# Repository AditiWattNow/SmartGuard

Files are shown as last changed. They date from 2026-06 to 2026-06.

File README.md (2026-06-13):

# SmartGuard — AI-Powered Railway Platform Crowd Safety System

> **Hackathon Project** | Hardware + Software | Indian Railways Safety Track

SmartGuard Dashboard

## The Problem

On **February 15, 2025**, a crowd crush at New Delhi Railway Station killed **18 people** and injured 15 others — triggered by train delays creating dangerous platform overcrowding. Indian Railways subsequently identified **60 high-traffic stations** requiring immediate crowd management upgrades.

Existing solutions react *after* dangerous density is reached. SmartGuard **predicts** breaches before they happen.

---

## What SmartGuard Does

| Layer | What it is |
|---|---|
| **Hardware** | Custom PCB sensor node (ESP32-S3 + PIR + ToF + LoRa) per zone |
| **Backend** | FastAPI server with time-series crowd data + anomaly detection |
| **Dashboard** | Live SVG station map + real-time alerts + trend prediction |
| **AI Model** | Linear regression slope on 5-reading window → estimated minutes to breach |

**Key differentiator:** SmartGuard gives station operators an **8–15 minute warning** before a dangerous threshold is reached — time to open alternate gates, redirect crowds, or delay train boarding. Real-time monitoring only tells you what's *already* happening.

---

## Architecture

```
[ESP32-S3 Node] ──WiFi/LoRa──▶ [FastAPI Backend] ──REST──▶ [Dashboard]
    ↑                                   ↓
PIR + VL53L1X                    SQLite DB
sensors                          Prediction Engine
                                 Alert Generator
```

**Kavach 4.0 compatible:** SmartGuard data format is designed for integration with Indian Railways' existing Kavach ATP system API. Kavach prevents train collisions — SmartGuard prevents platform crush. They are complementary, not competing.

---

## Repository Structure

```
smartguard/
├── backend/
│   ├── main.py              # FastAPI server — all 4 endpoints
│   └── requirements.txt
├── firmware/
│   └── smartguard_node.ino  # ESP32-S3 Arduino sketch
├── frontend/
│   └── index.html           # Complete single-file dashboard
├── hardware/                # KiCad PCB project (your partner's domain)
│   ├── smartguard_node.kicad_sch
│   ├── smartguard_node.kicad_pcb
│   └── gerbers/
└── docs/
    ├── architecture.png
    └── deployment-spec.md
```

---

## Running Locally

### Backend

```bash
cd backend
pip install -r requirements.txt
uvicorn main:app --reload --host 0.0.0.0 --port 8000
```

The server starts with:
- **Seeded historical data** (2 hours of realistic crowd patterns)
- **Mock sensor simulator** running in background — no hardware needed for demo
- **SQLite database** (`smartguard.db`) auto-created on first run

### Frontend

Just open `frontend/index.html` in a browser. No build step needed.

> If you get CORS errors, make sure the backend is running on `localhost:8000` (default).  
> For deployment, update `const API = "..."` in `index.html` to your server URL.

---

## API Endpoints

| Method | Endpoint | Description |
|---|---|---|
| `POST` | `/sensor` | Receive data from ESP32 nodes |
| `GET`  | `/zones` | Live crowd state for all zones |
| `GET`  | `/history/{zone_id}?minutes=60` | Time-series data for chart |
| `GET`  | `/alerts?limit=20` | Recent alert feed |
| `GET`  | `/stats/summary` | Header KPI cards |

### Example sensor POST (from ESP32 or test):
```bash
curl -X POST http://localhost:8000/sensor \
  -H "Content-Type: application/json" \
  -d '{"zone_id": "P1", "count": 145}'
```

---

## Zone Configuration

Zones are defined in `backend/main.py`:

```python
ZONES = {
    "P1": {"name": "Platform 1 - Gate A", "capacity": 200, ...},
    "P2": {"name": "Platform 2 - Gate B", "capacity": 180, ...},
    "C1": {"name": "Central Concourse",   "capacity": 400, ...},
    ...
}

THRESHOLDS = {"safe": 0.60, "warning": 0.80}  # fraction of capacity
```

Modify these to match any real station's layout.

---

## Prediction Model

SmartGuard uses a **least-squares linear regression** on the 10 most recent readings per zone:

1. Compute slope (people/second) from the time-series
2. If slope is positive, estimate seconds until 80% capacity threshold
3. Convert to minutes and surface in the UI as "Breach in ~N min"

This is equivalent to `sklearn.linear_model.LinearRegression` on a rolling window. For production, this can be upgraded to `IsolationForest` for anomaly detection or an LSTM for multi-step forecasting.

---

## Hardware BOM (per node) — ~₹2,500

| Component | Part | ~Cost |
|---|---|---|
| MCU | ESP32-S3 DevKitC | ₹800 |
| Motion sensor × 2 | HC-SR501 PIR | ₹80 |
| Distance sensor | VL53L1X ToF | ₹350 |
| Radio | SX1276 LoRa module | ₹450 |
| Battery management | TP4056 IC | ₹40 |
| PCB fabrication (JLCPCB) | 4-layer, 5 units | ₹600 |
| Misc (caps, LEDs, headers) | — | ₹180 |

**60 stations × avg 8 nodes = 480 nodes × ₹2,500 = ₹12 lakh total hardware cost.**
This is the cost of one Kavach installation on a 1km track segment.

---

## Deployment Path

1. **Phase 1 — Pilot** (3 months): Install at 2 platforms of New Delhi station. Validate prediction accuracy against manual crowd counts.
2. **Phase 2 — Refinement** (3 months): Tune thresholds, integrate train delay API for better surge prediction.
3. **Phase 3 — Rollout** (6 months): Deploy to 60 identified high-risk stations. Integrate alerts into station master control room.

---

## Team

| Role | Responsibility |
|---|---|
| Hardware Engineer | PCB design (KiCad), ESP32 firmware, sensor integration |
| Software Engineer | FastAPI backend, React dashboard, deployment |

---

## License

MIT License — open for Indian Railways adoption and modification.

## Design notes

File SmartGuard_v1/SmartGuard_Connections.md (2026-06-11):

# SmartGuard v1 — PCB Connection Reference

## Project Overview
AI-powered railway platform crowd crush prevention system.
Custom PCB sensor node for real-time crowd density monitoring.

---

## Bill of Materials (BOM)

| Ref | Component | Package | Value | Source |
|-----|---|---|---|---|
| U1 | ESP32-S3-WROOM-1 | SMD Castellated | Main MCU | Robu.in |
| U2 | VL53L1X Breakout | 6-pin header | ToF depth sensor | Thingbits.in |
| U3 | RFM95W-868S2 | SMD Module | LoRa 868MHz radio | Evelta.com |
| U4 | TP4056 Module | External module | LiPo charger 1A | Robu.in |
| U5 | LM7833 / AMS1117-3.3 | TO-220 THT | 3.3V LDO regulator | SP Road |
| R1 | Resistor | THT axial | 10kΩ | SP Road |
| R2 | Resistor | THT axial | 4.7kΩ | SP Road |
| R3 | Resistor | THT axial | 4.7kΩ | SP Road |
| R4 | Resistor | THT axial | 100Ω | SP Road |
| R5 | Resistor | THT axial | 1.2kΩ | SP Road |
| R6 | Resistor | THT axial | 100Ω | SP Road |
| R7 | Resistor | THT axial | 100Ω | SP Road |
| C1 | Ceramic Cap | THT disc | 100nF | SP Road |
| C2 | Ceramic Cap | THT disc | 100nF | SP Road |
| C3 | Ceramic Cap | THT disc | 100nF | SP Road |
| C4 | Electrolytic Cap | THT radial | 10µF | SP Road |
| C5 | Ceramic Cap | THT disc | 100nF | SP Road |
| D1 | LED Red | THT 5mm | Status indicator | SP Road |
| D2 | LED Amber | THT 5mm | Status indicator | SP Road |
| D3 | LED Green | THT 5mm | Status indicator | SP Road |
| J1 | PIR-A Connector | PinHeader 2.54mm 3-pin | HC-SR501 Zone A | SP Road |
| J2 | PIR-B Connector | PinHeader 2.54mm 3-pin | HC-SR501 Zone B | SP Road |
| J4 | LiPo Connector | JST-PH 2mm 2-pin | 3.7V 2000mAh battery | Robu.in |
| AE1 | Antenna | SMA EdgeMount | 868MHz wire antenna | SP Road |
| — | HC-SR501 × 2 | External module | PIR motion sensors | Robu.in |

**Estimated total cost: ₹2000–2500**

---

## Pin Assignments — ESP32-S3-WROOM-1

### I2C Bus (VL53L1X ToF sensor)
| ESP32-S3 Pin | Signal | Connected To |
|---|---|---|
| IO4 | I2C_SDA | VL53L1X SDA + 4.7kΩ pullup to 3V3 |
| IO5 | I2C_SCL | VL53L1X SCL + 4.7kΩ pullup to 3V3 |
| IO8 | TOF_XSHUT | VL53L1X XSHUT |

### SPI Bus (RFM95W LoRa)
| ESP32-S3 Pin | Signal | Connected To |
|---|---|---|
| IO18 | SPI_MOSI | RFM95W MOSI |
| IO35 | SPI_MISO | RFM95W MISO |
| IO38 | SPI_SCK | RFM95W SCK |
| IO21 | LORA_NSS | RFM95W NSS (chip select) |
| IO41 | LORA_RST | RFM95W RESET |
| IO9 | LORA_DIO0 | RFM95W DIO0 (interrupt) |

### GPIO (PIR sensors)
| ESP32-S3 Pin | Signal | Connected To |
|---|---|---|
| IO6 | PIR_A | HC-SR501 Zone A OUT |
| IO7 | PIR_B | HC-SR501 Zone B OUT |

### GPIO (Status LEDs)
| ESP32-S3 Pin | Signal | Connected To |
|---|---|---|
| IO46 | LED_RED | 100Ω resistor → Red LED anode |
| IO42 | LED_AMB | 100Ω resistor → Amber LED anode |
| IO47 | LED_GRN | 100Ω resistor → Green LED anode |

### Power
| ESP32-S3 Pin | Connected To |
|---|---|
| 3V3 | +3V3 power rail |
| GND | GND |
| EN | 10kΩ pullup to +3V3 |

---

## VL53L1X Breakout Board Connections

| VL53L1X Pin | Connected To |
|---|---|
| VDD | +3V3 |
| GND | GND |
| SDA | I2C_SDA (IO4) |
| SCL | I2C_SCL (IO5) |
| XSHUT | TOF_XSHUT (IO8) |
| GPIO1 | Not connected |

**I2C Address:** 0x29

---

## RFM95W-868S2 LoRa Module Connections

| RFM95W Pin | Connected To |
|---|---|
| 3.3V | +3V3 |
| GND | GND |
| MOSI | SPI_MOSI (IO18) |
| MISO | SPI_MISO (IO35) |
| SCK | SPI_SCK (IO38) |
| NSS | LORA_NSS (IO21) |
| RESET | LORA_RST (IO41) |
| DIO0 | LORA_DIO0 (IO9) |
| ANT | 8.2cm wire antenna (868MHz) |
| DIO1–DIO5 | Not connected |

**Frequency:** 868 MHz (India ISM band approved)
**Antenna:** 8.2cm straight wire for 868MHz λ/4

---

## HC-SR501 PIR Sensor Connections (×2)

| HC-SR501 Pin | Zone A | Zone B |
|---|---|---|
| VCC | +5V | +5V |
| GND | GND | GND |
| OUT | PIR_A (IO6) | PIR_B (IO7) |

**Note:** HC-SR501 OUT is 3.3V logic — safe for direct ESP32 GPIO connection.
**Sensitivity:** Adjust onboard potentiometer to ~3 metre range.
**Delay:** Set onboard delay pot to minimum (~5 seconds).

---

## Power Section

### TP4056 Charging Module
| TP4056 Module Pin | Connected To |
|---|---|
| USB input | External USB-C/Micro-USB (onboard) |
| B+ | LiPo battery positive (JST J4 pin 1) |
| B- | LiPo battery negative (JST J4 pin 2) / GND |
| OUT+ (VBAT) | LM7833 input (VI pin) |
| OUT- | GND |

**Charge current:** 1A (set by 1.2kΩ PROG resistor)

### LM7833 / AMS1117-3.3 Voltage Regulator (TO-220)
| LM7833 Pin | Connected To |
|---|---|
| VI (input) | VBAT from TP4056 OUT+ |
| VO (output) | +3V3 power rail |
| GND | GND |

**Input cap:** 10µF (C4) from VBAT to GND
**Output cap:** 100nF (C5) from +3V3 to GND

---

## Decoupling Capacitors

| Cap | Value | Placed Near | Between |
|---|---|---|---|
| C1 | 100nF | VL53L1X VDD pin | +3V3 and GND |
| C2 | 100nF | RFM95W 3.3V pin | +3V3 and GND |
| C3 | 100nF | TP4056 VCC pin | +5V and GND |
| C4 | 10µF | LM7833 input | VBAT and GND |
| C5 | 100nF | LM7833 output | +3V3 and GND |

---

## I2C Pull-up Resistors

| Resistor | Value | Connected Between |
|---|---|---|
| R2 | 4.7kΩ | I2C_SDA and +3V3 |
| R3 | 4.7kΩ | I2C_SCL and +3V3 |

---

## Status LED Circuit

| LED | Color | Resistor | GPIO |
|---|---|---|---|
| D1 | Red | R4 100Ω | IO46 |
| D2 | Amber | R6 100Ω | IO42 |
| D3 | Green | R7 100Ω | IO47 |

**Meaning:**
- 🟢 Green = Safe — crowd density normal
- 🟡 Amber = Warning — density rising, monitor
- 🔴 Red = Alert — critical density, trigger PA system

---

## Firmware Pin Definitions

```cpp
// ============================================
// SmartGuard v1 — Pin Definitions
// ESP32-S3-WROOM-1
// ============================================

// I2C — VL53L1X ToF sensor
#define I2C_SDA     4
#define I2C_SCL     5
#define TOF_XSHUT   8

// SPI — RFM95W LoRa
#define LORA_MOSI   18
#define LORA_MISO   35
#define LORA_SCK    38
#define LORA_NSS    21
#define LORA_RST    41
#define LORA_DIO0   9

// PIR sensors
#define PIR_A       6
#define PIR_B       7

// Status LEDs
#define LED_RED     46
#define LED_AMB     42
#define LED_GRN     47

// LoRa settings
#define LORA_FREQ   868E6   // 868 MHz India ISM band
```

---

## Power Rails Summary

| Rail | Voltage | Source | Powers |
|---|---|---|---|
| +5V | 5V | USB via TP4056 module | HC-SR501 PIR sensors |
| VBAT | 3.7V nominal | LiPo battery | LM7833 input |
| +3V3 | 3.3V | LM7833 regulator | ESP32-S3, VL53L1X, RFM95W |
| GND | 0V | Common ground | All components |

---

## PCB Design Rules Used

| Parameter | Value |
|---|---|
| Minimum track width | 0.2mm |
| Signal track width | 0.25mm |
| Power track width | 0.5mm |
| Minimum clearance | 0.2mm |
| Via diameter | 0.8mm |
| Via drill | 0.4mm |
| Board thickness | 1.6mm |
| Copper layers | 2 (F.Cu signals, B.Cu ground plane) |
| Board dimensions | ~100mm × 75mm |

---

## GitHub Repository Structure

```
SmartGuard_v1/
├── hardware/
│   ├── SmartGuard_v1.kicad_pro
│   ├── SmartGuard_v1.kicad_sch
│   ├── SmartGuard_v1.kicad_pcb
│   └── gerbers/
│       ├── SmartGuard_v1-F_Cu.gbr
│       ├── SmartGuard_v1-B_Cu.gbr
│       ├── SmartGuard_v1-F_Silkscreen.gbr
│       ├── SmartGuard_v1-Edge_Cuts.gbr
│       └── SmartGuard_v1-drill.drl
├── firmware/
│   └── smartguard_firmware/
│       ├── smartguard_firmware.ino
│       └── pins.h
├── software/
│   ├── backend/
│   └── dashboard/
├── docs/
│   ├── architecture_diagram.png
│   ├── schematic.pdf
│   └── BOM.csv
└── README.md
```

---

*SmartGuard v1 — Far Away Hackathon 2026*
*Theme: Railways — Build systems that make railways safer, smarter and more efficient*

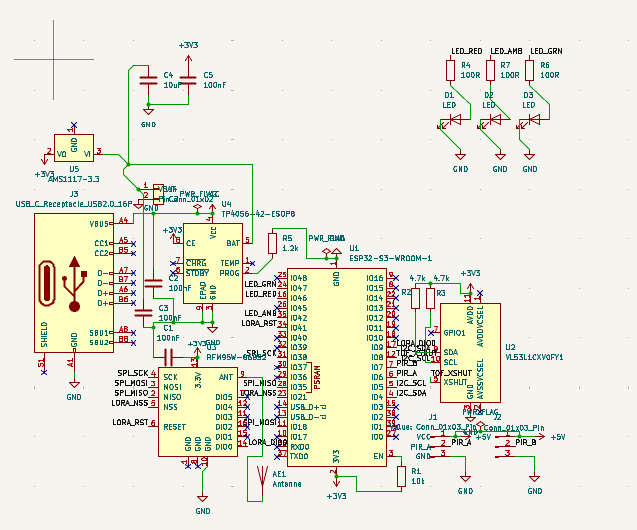
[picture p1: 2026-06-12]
docs/schematic.png

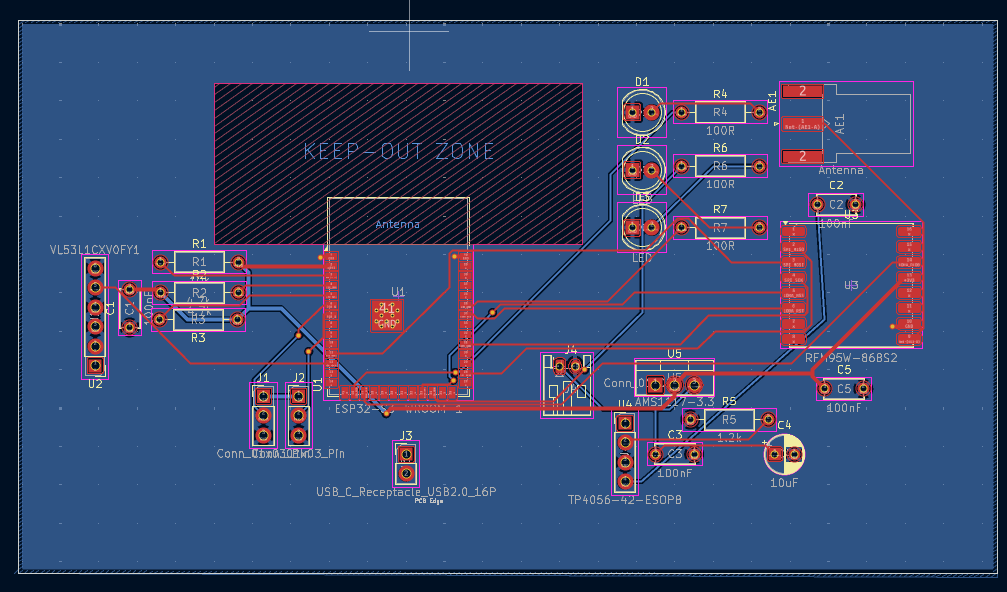
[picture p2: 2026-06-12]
docs/pcb.png

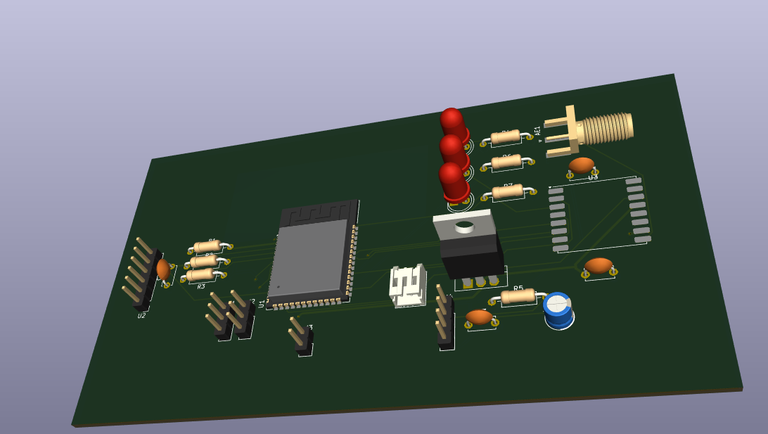
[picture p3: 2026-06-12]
docs/3-D.png

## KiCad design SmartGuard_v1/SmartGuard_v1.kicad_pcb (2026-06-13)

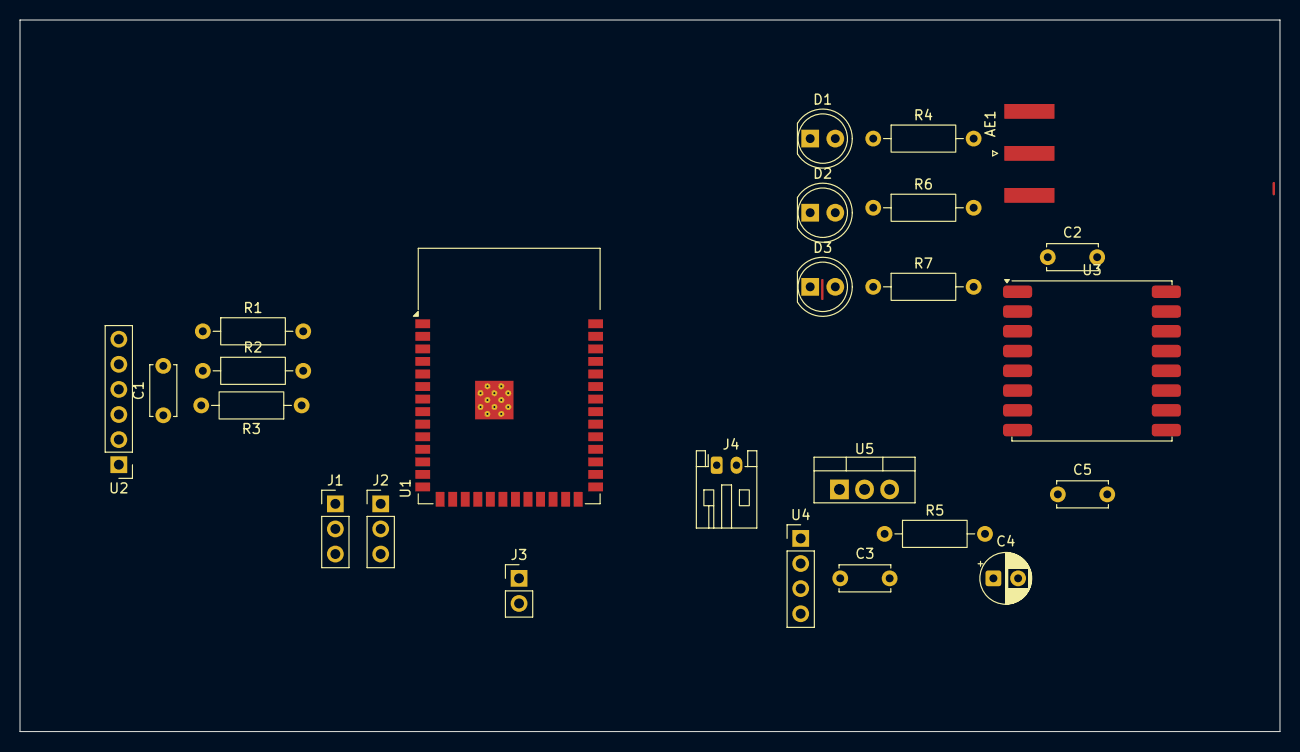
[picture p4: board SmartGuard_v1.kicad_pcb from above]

Board: 2 copper layers, 127.5 x 72.0 mm, 25 parts (0 on the bottom side), 25 nets.

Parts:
AE1: Antenna; SMA_Amphenol_132289_EdgeMount
C1, C2, C3, C5: 100nF; C_Disc_D5.0mm_W2.5mm_P5.00mm
C4: 10uF; CP_Radial_D5.0mm_P2.50mm
D1, D2, D3: LED; LED_D5.0mm
J1, J2: Conn_01x03_Pin; PinHeader_1x03_P2.54mm_Vertical
J3: USB_C_Receptacle_USB2.0_16P; PinHeader_1x02_P2.54mm_Vertical
J4: Conn_01x02; JST_PH_S2B-PH-K_1x02_P2.00mm_Horizontal
R1: 10k; R_Axial_DIN0207_L6.3mm_D2.5mm_P10.16mm_Horizontal
R2, R3: 4.7k; R_Axial_DIN0207_L6.3mm_D2.5mm_P10.16mm_Horizontal
R4, R6, R7: 100R; R_Axial_DIN0207_L6.3mm_D2.5mm_P10.16mm_Horizontal
R5: 1.2k; R_Axial_DIN0207_L6.3mm_D2.5mm_P10.16mm_Horizontal
U1: ESP32-S3-WROOM-1
U2: VL53L1CXV0FY1; PinHeader_1x06_P2.54mm_Vertical
U3: RFM95W-868S2; HOPERF_RFM9XW_SMD
U4: TP4056-42-ESOP8; PinHeader_1x04_P2.54mm_Vertical
U5: AMS1117-3.3; TO-220-3_Vertical

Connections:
+3V3: C1.2, C5.1, R1.2, R2.1, R3.1, U1.2 (3V3), U3.13 (3.3V), U5.2 (VO)
+5V: J1.1 (VCC), J2.1 (VCC)
/I2C_SCL: R3.2, U1.5 (IO5)
/I2C_SDA: R2.2, U1.4 (IO4)
/LED_AMB: R7.1, U1.35 (IO42)
/LED_GRN: R6.1, U1.24 (IO47)
/LED_RED: R4.1, U1.16 (IO46)
/LORA_DIO0: U1.17 (IO9), U3.14 (DIO0)
/LORA_NSS: U1.23 (IO21), U3.5 (NSS)
/LORA_RST: U1.34 (IO41), U3.6 (RESET)
/PIR_A: J1.2 (PIR_A), U1.6 (IO6)
/PIR_B: J2.2 (PIR_B), U1.7 (IO7)
/SPI_MISO: U1.28 (IO35), U3.2 (MISO)
/SPI_MOSI: U1.11 (IO18), U3.3 (MOSI)
/SPI_SCK: U1.31 (IO38), U3.4 (SCK)
/TOF_XSHUT: U1.12 (IO8), U2.5 (XSHUT)
GND: C1.1, C2.2, C3.2, C4.2, C5.2, D1.1 (K), D2.1 (K), D3.1 (K), J1.3 (GND), J2.3 (GND), J4.2, R5.1, U1.1 (GND), U1.40 (GND), U1.41 (GND), U2.3 (GND), U2.4 (GND), U2.6 (GND), U3.10 (GND), U4.3 (GND)
unnamed: AE1.1 (A), U3.9 (ANT)
unnamed: D1.2 (A), R4.2
unnamed: D2.2 (A), R7.2
unnamed: D3.2 (A), R6.2
unnamed: C3.1, C4.1, J4.1 (VBAT), U5.3 (VI)
unnamed: R1.1, U1.3 (EN)
unnamed: R5.2, U4.2 (PROG)
VCC: C2.1, U4.4 (V_{CC})

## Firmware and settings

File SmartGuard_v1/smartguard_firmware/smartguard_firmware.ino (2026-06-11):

// ============================================
// SmartGuard v1 — Firmware
// ESP32-S3-WROOM-1
// Far Away Hackathon 2026
// Theme: Railways
// ============================================

#include <Wire.h>
#include <VL53L1X.h>
#include <SPI.h>
#include <LoRa.h>
#include <ArduinoJson.h>

// ============================================
// PIN DEFINITIONS
// ============================================

// I2C - VL53L1X
#define I2C_SDA       4
#define I2C_SCL       5
#define TOF_XSHUT     8

// SPI - RFM95W LoRa
#define LORA_MOSI     18
#define LORA_MISO     35
#define LORA_SCK      38
#define LORA_NSS      21
#define LORA_RST      41
#define LORA_DIO0     9

// PIR Sensors
#define PIR_A         6
#define PIR_B         7

// Status LEDs
#define LED_RED       46
#define LED_AMB       42
#define LED_GRN       47

// ============================================
// CONFIGURATION
// ============================================

#define LORA_FREQ         868E6    // 868 MHz India ISM band
#define NODE_ID           "PF_01"  // Platform node ID - change per node
#define SEND_INTERVAL     30000    // Send data every 30 seconds
#define DENSITY_THRESHOLD_AMBER  10  // People count for amber alert
#define DENSITY_THRESHOLD_RED    20  // People count for red alert

// VL53L1X distance thresholds (mm)
// Anything closer than this = person detected in doorway
#define PERSON_DISTANCE   1200     // 1.2 metres

// ============================================
// GLOBAL VARIABLES
// ============================================

VL53L1X tofSensor;

int peopleCount     = 0;    // Running total of people on platform
int peopleIn        = 0;    // People entered this interval
int peopleOut       = 0;    // People exited this interval
bool lastBeamState  = false;// Last state of ToF beam
bool pirAState      = false;
bool pirBState      = false;
unsigned long lastSendTime  = 0;
unsigned long lastTofRead   = 0;
String alertLevel   = "GREEN";

// ============================================
// SETUP
// ============================================

void setup() {
  Serial.begin(115200);
  Serial.println("SmartGuard v1 — Booting...");

  // LED pins
  pinMode(LED_RED, OUTPUT);
  pinMode(LED_AMB, OUTPUT);
  pinMode(LED_GRN, OUTPUT);

  // PIR pins
  pinMode(PIR_A, INPUT);
  pinMode(PIR_B, INPUT);

  // Boot indicator — flash all LEDs
  flashAllLEDs(3);

  // Initialise I2C
  Wire.begin(I2C_SDA, I2C_SCL);
  Serial.println("I2C initialised");

  // Initialise VL53L1X
  pinMode(TOF_XSHUT, OUTPUT);
  digitalWrite(TOF_XSHUT, LOW);
  delay(10);
  digitalWrite(TOF_XSHUT, HIGH);
  delay(10);

  tofSensor.setTimeout(500);
  if (!tofSensor.init()) {
    Serial.println("ERROR: VL53L1X not found!");
    errorBlink(LED_RED);  // Fast red blink = sensor error
  } else {
    Serial.println("VL53L1X initialised");
    tofSensor.setDistanceMode(VL53L1X::Long);
    tofSensor.setMeasurementTimingBudget(50000);
    tofSensor.startContinuous(50);
  }

  // Initialise LoRa
  SPI.begin(LORA_SCK, LORA_MISO, LORA_MOSI, LORA_NSS);
  LoRa.setPins(LORA_NSS, LORA_RST, LORA_DIO0);

  if (!LoRa.begin(LORA_FREQ)) {
    Serial.println("ERROR: LoRa not found!");
    errorBlink(LED_AMB);  // Fast amber blink = LoRa error
  } else {
    Serial.println("LoRa initialised at 868 MHz");
    LoRa.setSpreadingFactor(9);       // SF9 - good range/speed balance
    LoRa.setSignalBandwidth(125E3);   // 125 kHz bandwidth
    LoRa.setCodingRate4(5);           // 4/5 coding rate
    LoRa.setTxPower(17);              // 17 dBm transmit power
  }

  // Ready — show green
  setLED("GREEN");
  Serial.println("SmartGuard ready!");
  Serial.print("Node ID: ");
  Serial.println(NODE_ID);
}

// ============================================
// MAIN LOOP
// ============================================

void loop() {
  unsigned long now = millis();

  // Read ToF sensor every 100ms
  if (now - lastTofRead >= 100) {
    readToFSensor();
    lastTofRead = now;
  }

  // Read PIR sensors
  pirAState = digitalRead(PIR_A);
  pirBState = digitalRead(PIR_B);

  // Calculate density and update LEDs
  updateAlertLevel();

  // Send LoRa packet every 30 seconds
  if (now - lastSendTime >= SEND_INTERVAL) {
    sendLoRaPacket();
    lastSendTime = now;
  }
}

// ============================================
// TOF SENSOR — PEOPLE COUNTING
// ============================================

void readToFSensor() {
  if (!tofSensor.dataReady()) return;

  int distance = tofSensor.read();

  // Person detected if closer than threshold
  bool beamBroken = (distance < PERSON_DISTANCE);

  // Rising edge — person just walked into beam
  if (beamBroken && !lastBeamState) {
    // Simple direction detection using PIR
    // If PIR_A triggered recently = entering platform
    // If PIR_B triggered recently = exiting platform
    if (pirAState) {
      peopleCount++;
      peopleIn++;
      Serial.print("Person IN — Total: ");
      Serial.println(peopleCount);
    } else if (pirBState) {
      if (peopleCount > 0) peopleCount--;
      peopleOut++;
      Serial.print("Person OUT — Total: ");
      Serial.println(peopleCount);
    } else {
      // Default — assume entering
      peopleCount++;
      peopleIn++;
      Serial.print("Person detected — Total: ");
      Serial.println(peopleCount);
    }
  }

  lastBeamState = beamBroken;
}

// ============================================
// ALERT LEVEL + LED CONTROL
// ============================================

void updateAlertLevel() {
  if (peopleCount >= DENSITY_THRESHOLD_RED) {
    alertLevel = "RED";
    setLED("RED");
  } else if (peopleCount >= DENSITY_THRESHOLD_AMBER) {
    alertLevel = "AMBER";
    setLED("AMBER");
  } else {
    alertLevel = "GREEN";
    setLED("GREEN");
  }
}

void setLED(String level) {
  // Turn all off first
  digitalWrite(LED_RED, LOW);
  digitalWrite(LED_AMB, LOW);
  digitalWrite(LED_GRN, LOW);

  if (level == "RED")   digitalWrite(LED_RED, HIGH);
  if (level == "AMBER") digitalWrite(LED_AMB, HIGH);
  if (level == "GREEN") digitalWrite(LED_GRN, HIGH);
}

// ============================================
// LORA TRANSMISSION
// ============================================

void sendLoRaPacket() {
  // Build JSON payload
  StaticJsonDocument<256> doc;
  doc["node"]    = NODE_ID;
  doc["count"]   = peopleCount;
  doc["in"]      = peopleIn;
  doc["out"]     = peopleOut;
  doc["alert"]   = alertLevel;
  doc["pir_a"]   = pirAState;
  doc["pir_b"]   = pirBState;
  doc["uptime"]  = millis() / 1000;

  String payload;
  serializeJson(doc, payload);

  // Send via LoRa
  LoRa.beginPacket();
  LoRa.print(payload);
  LoRa.endPacket();

  Serial.print("LoRa sent: ");
  Serial.println(payload);

  // Reset interval counters
  peopleIn  = 0;
  peopleOut = 0;
}

// ============================================
// UTILITY FUNCTIONS
// ============================================

void flashAllLEDs(int times) {
  for (int i = 0; i < times; i++) {
    digitalWrite(LED_RED, HIGH);
    digitalWrite(LED_AMB, HIGH);
    digitalWrite(LED_GRN, HIGH);
    delay(200);
    digitalWrite(LED_RED, LOW);
    digitalWrite(LED_AMB, LOW);
    digitalWrite(LED_GRN, LOW);
    delay(200);
  }
}

void errorBlink(int pin) {
  // Fast blink forever to indicate error
  Serial.println("HALTED — Check sensor connection");
  while (true) {
    digitalWrite(pin, HIGH);
    delay(100);
    digitalWrite(pin, LOW);
    delay(100);
  }
}

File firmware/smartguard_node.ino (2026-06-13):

/*
 * SmartGuard — ESP32-S3 Sensor Node Firmware
 * Reads PIR + VL53L1X sensors and posts JSON to FastAPI backend via WiFi
 *
 * Hardware:
 *   - ESP32-S3 DevKitC
 *   - 2x HC-SR501 PIR sensors (GPIO 4, GPIO 5)
 *   - VL53L1X ToF sensor (I2C: SDA=GPIO21, SCL=GPIO22)
 *   - SX1276 LoRa module (SPI: MOSI=GPIO23, MISO=GPIO19, SCK=GPIO18, CS=GPIO5)
 *
 * Dependencies (install via Arduino Library Manager):
 *   - ArduinoJson by Benoit Blanchon
 *   - VL53L1X by Pololu
 *   - LoRa by Sandeep Mistry
 */

#include <WiFi.h>
#include <HTTPClient.h>
#include <ArduinoJson.h>
#include <Wire.h>
#include "VL53L1X.h"

// ── Config ─────────────────────────────────────────────────────────────────
const char* WIFI_SSID     = "YOUR_SSID";
const char* WIFI_PASSWORD = "YOUR_PASSWORD";
const char* API_URL       = "http://YOUR_SERVER_IP:8000/sensor";
const char* ZONE_ID       = "P1";   // Change per node: P1, P2, P3, C1, E1

// GPIO
const int PIR_PIN_1 = 4;
const int PIR_PIN_2 = 5;
const int LED_SAFE  = 25;
const int LED_WARN  = 26;
const int LED_DANGER= 27;

// Timing
const unsigned long POST_INTERVAL_MS = 5000;   // post every 5 seconds

// ── Globals ─────────────────────────────────────────────────────────────────
VL53L1X tof;
unsigned long lastPost   = 0;
int           peopleCount = 0;
bool          pir1Active = false;
bool          pir2Active = false;

// ── Simple people counter using PIR pair (entry/exit beam logic) ──────────
// PIR1 triggers first → entering; PIR2 triggers first → exiting
unsigned long pir1Time = 0;
unsigned long pir2Time = 0;

void IRAM_ATTR onPIR1() {
  pir1Time = millis();
  pir1Active = true;
}

void IRAM_ATTR onPIR2() {
  pir2Time = millis();
  pir2Active = true;
}

void processPIR() {
  const unsigned long WINDOW = 2000;   // 2 second window

  if (pir1Active && pir2Active) {
    if (pir1Time < pir2Time && (pir2Time - pir1Time) < WINDOW) {
      peopleCount = max(0, peopleCount + 1);   // entered
    } else if (pir2Time < pir1Time && (pir1Time - pir2Time) < WINDOW) {
      peopleCount = max(0, peopleCount - 1);   // exited
    }
    pir1Active = pir2Active = false;
  }
}

void setStatusLED(int count, int capacity) {
  float ratio = (float)count / capacity;
  digitalWrite(LED_SAFE,   LOW);
  digitalWrite(LED_WARN,   LOW);
  digitalWrite(LED_DANGER, LOW);

  if      (ratio >= 0.80) digitalWrite(LED_DANGER, HIGH);
  else if (ratio >= 0.60) digitalWrite(LED_WARN,   HIGH);
  else                    digitalWrite(LED_SAFE,   HIGH);
}

void postToAPI(int count) {
  if (WiFi.status() != WL_CONNECTED) return;

  HTTPClient http;
  http.begin(API_URL);
  http.addHeader("Content-Type", "application/json");

  StaticJsonDocument<128> doc;
  doc["zone_id"] = ZONE_ID;
  doc["count"]   = count;

  String body;
  serializeJson(doc, body);

  int code = http.POST(body);
  if (code == 200) {
    Serial.printf("[SmartGuard] Posted: zone=%s count=%d → HTTP %d\n",
                  ZONE_ID, count, code);
  } else {
    Serial.printf("[SmartGuard] POST failed: HTTP %d\n", code);
  }

  http.end();
}

// ── Setup ──────────────────────────────────────────────────────────────────
void setup() {
  Serial.begin(115200);
  Serial.println("[SmartGuard] Booting...");

  // PIR interrupts
  pinMode(PIR_PIN_1, INPUT);
  pinMode(PIR_PIN_2, INPUT);
  attachInterrupt(digitalPinToInterrupt(PIR_PIN_1), onPIR1, RISING);
  attachInterrupt(digitalPinToInterrupt(PIR_PIN_2), onPIR2, RISING);

  // Status LEDs
  pinMode(LED_SAFE,   OUTPUT);
  pinMode(LED_WARN,   OUTPUT);
  pinMode(LED_DANGER, OUTPUT);
  digitalWrite(LED_SAFE, HIGH);   // green on boot

  // VL53L1X ToF
  Wire.begin();
  tof.setTimeout(500);
  if (tof.init()) {
    tof.setDistanceMode(VL53L1X::Long);
    tof.setMeasurementTimingBudget(50000);
    tof.startContinuous(100);
    Serial.println("[SmartGuard] ToF sensor OK");
  } else {
    Serial.println("[SmartGuard] WARNING: ToF sensor not found, using PIR only");
  }

  // WiFi
  Serial.printf("[SmartGuard] Connecting to %s", WIFI_SSID);
  WiFi.begin(WIFI_SSID, WIFI_PASSWORD);
  while (WiFi.status() != WL_CONNECTED) {
    delay(500);
    Serial.print(".");
  }
  Serial.printf("\n[SmartGuard] WiFi connected — IP: %s\n",
                WiFi.localIP().toString().c_str());
}

// ── Loop ───────────────────────────────────────────────────────────────────
void loop() {
  processPIR();

  // ToF density check — if something is closer than 80cm, add to count
  if (tof.dataReady()) {
    int dist = tof.read();
    if (dist > 0 && dist < 800) {
      // object (person) detected within 80cm of sensor
      // This acts as a presence density cross-check
    }
    tof.clearInterrupt();
  }

  // Post to backend every POST_INTERVAL_MS
  if (millis() - lastPost >= POST_INTERVAL_MS) {
    postToAPI(peopleCount);
    setStatusLED(peopleCount, 200);   // 200 = this zone's capacity
    lastPost = millis();
  }

  delay(10);
}

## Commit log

2026-06-11 Add PCB design files and firmware
    [SmartGuard_v1-B_Cu.gbl, SmartGuard_v1-B_Mask.gbs, SmartGuard_v1-B_Paste.gbp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]
2026-06-12 Add PCB screenshots
2026-06-12 Add PCB preview images to README
2026-06-12 add sch, pcb, 3-D view
2026-06-13 Add KiCad hardware files to main
    [SmartGuard_v1-B_Cu.gbl, SmartGuard_v1-B_Mask.gbs, SmartGuard_v1-B_Paste.gbp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]
